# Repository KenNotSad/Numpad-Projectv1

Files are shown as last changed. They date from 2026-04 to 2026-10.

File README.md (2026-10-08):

# Numpad-Projectv1

This project is an RP2040-powered gasket-mount numpad with a rotary encoder and OLED display, intended to help me learn introductory PCB design and QMK firmware. 
<p align="center">
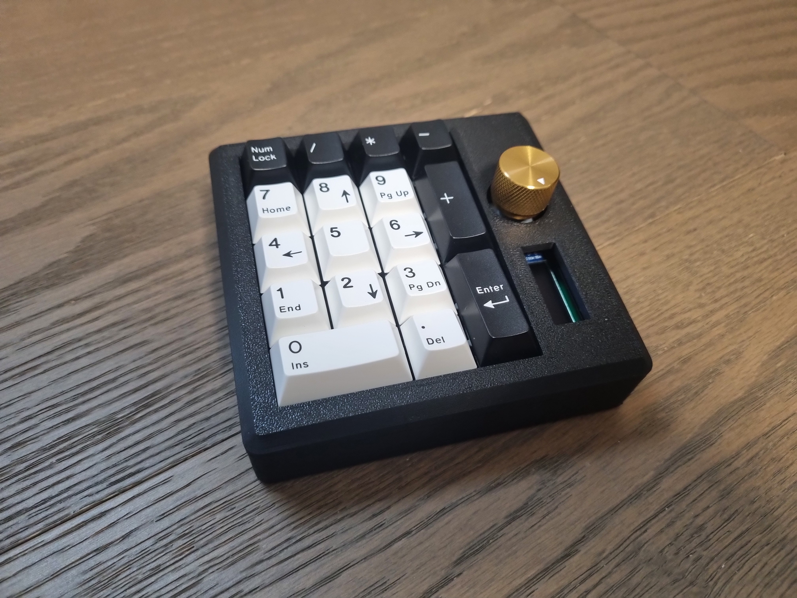
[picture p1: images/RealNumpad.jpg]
  
</p>

## Mechanical
<p align="center">
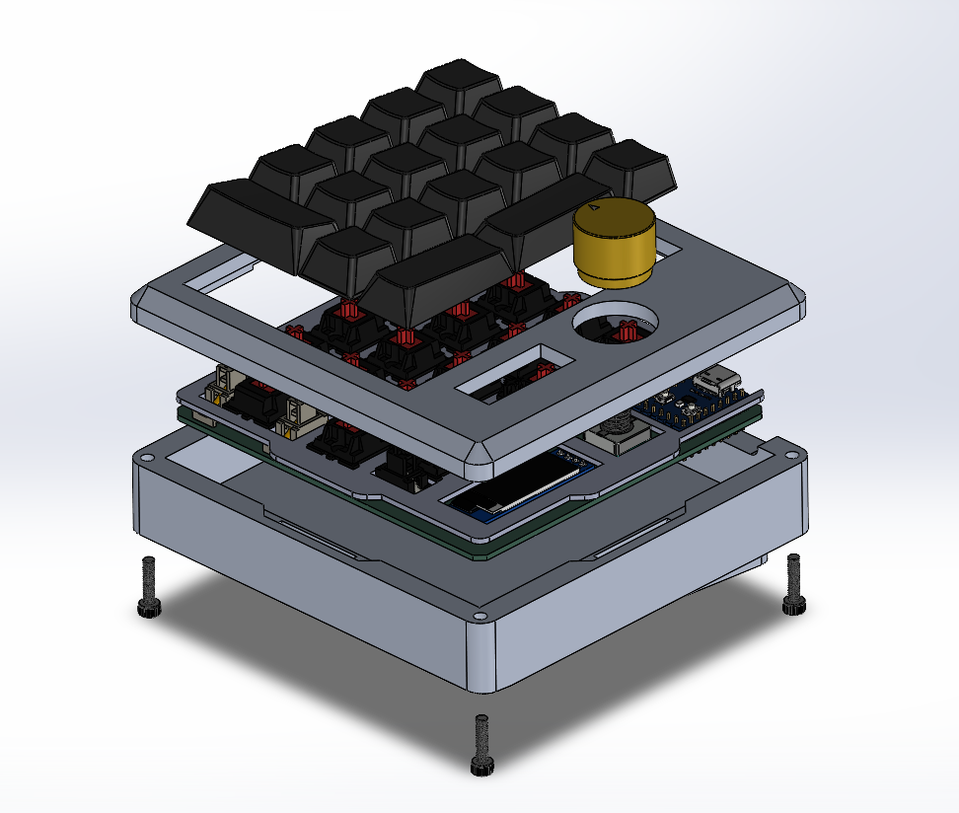
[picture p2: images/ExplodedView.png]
Exploded View
  
</p>
The top case, bottom case, and plate were designed in SolidWorks and 3D-printed. 

## Electrical
<p align="center">
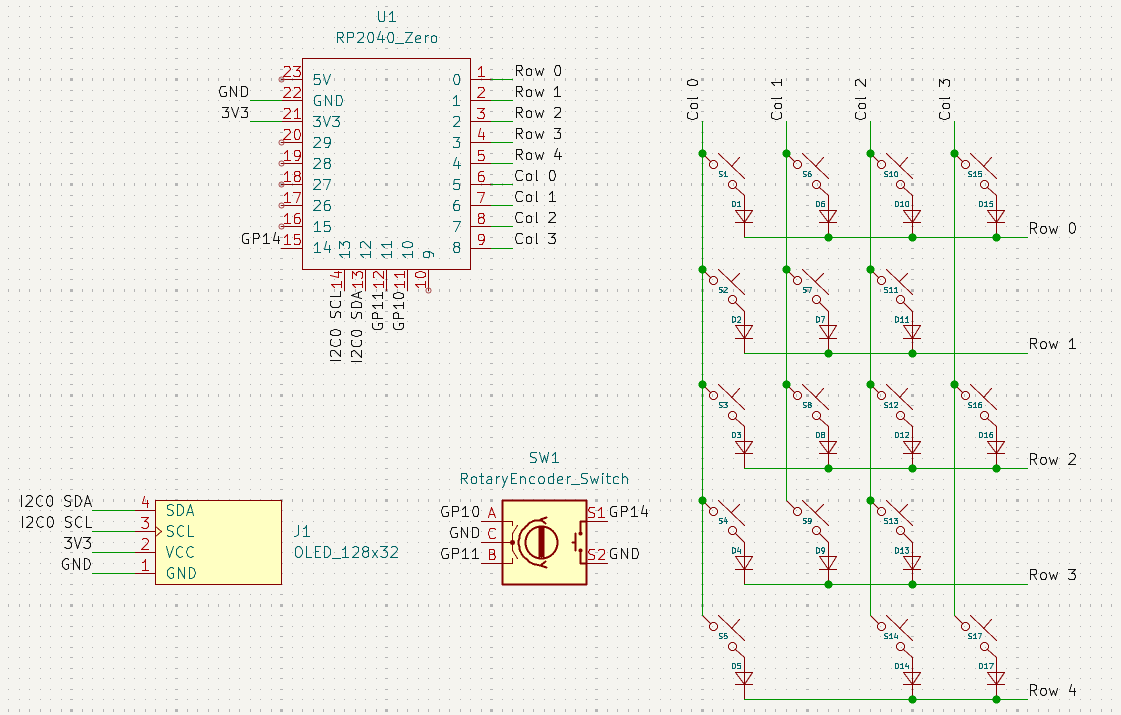
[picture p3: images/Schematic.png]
Schematic
  
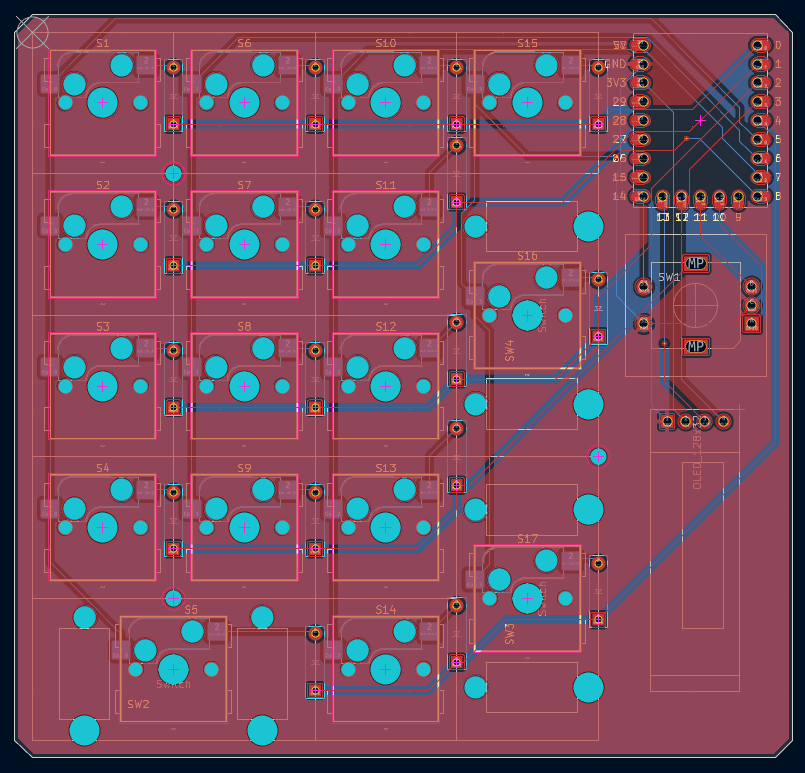
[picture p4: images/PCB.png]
PCB
  
</p>
Schematic and PCB were designed in KiCad and sent to be manufactured by JLCPCB. NOTE: The KiCad files rely on the ScottoKeebs KiCad Library. 

## Assembly

1. Solder RP2040 Zero, 1N4148 diodes, MX hotswap sockets, EC11 rotary encoder, 128X32 OLED display onto PCB
2. Add 3 2U screw-in stabilizers (1.6mm) to the PCB
3. Attach plate to PCB using 3mm standoffs and M2 x 3mm screws
4. Insert 17 MX switches into the assembly
5. Add 8 (4 on top case, 4 on bottom case) 3mm x 25mm x 1.5mm gaskets to the cases
6. Sandwich the plate between the top and bottom cases, and assemble using 4 M3 x 12mm screws
7. Add rubber feet (or tack) to the bottom case
8. Add keycaps and knob

Done!

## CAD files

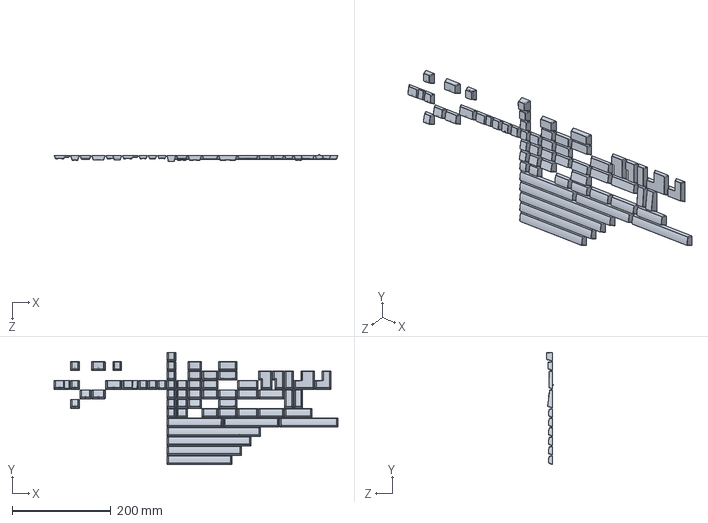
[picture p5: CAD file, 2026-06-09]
cad/Cherry Keycaps Full.SLDPRT
575.3 x 227.7 x 15.0 mm

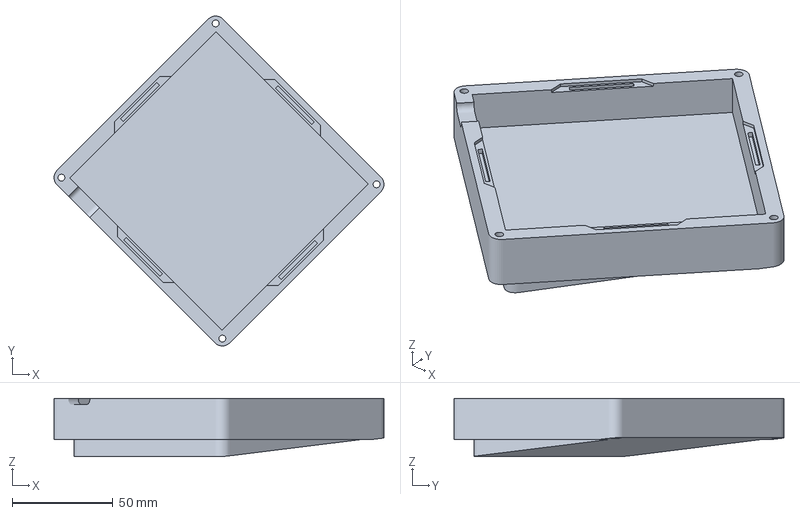
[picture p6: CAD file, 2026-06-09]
cad/Fabrication/BottomCasev1.3mf
163.5 x 163.5 x 29.0 mm

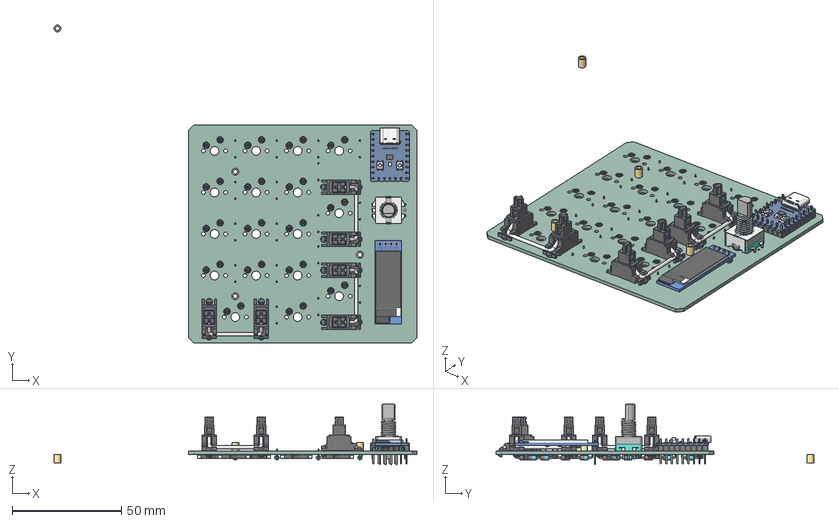
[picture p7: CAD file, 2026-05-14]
pcb/Numpadv1/PCB.step
166.5 x 145.9 x 27.8 mm
Hotswap_MX x 17
Stabilizer_MX_2.00u x 3
EC11
Standoff x 4
Raspberry_Pi_Pico.step
PinHeader_1x20_P2.54mm_Vertical.step
BOARD
ANSCHL_X_FCSSE_009
K_X_F6RPER_009
ANSCHL_X_FCSSE_010
K_X_F6RPER_010
EXTRUDED-32530
USER_LIBRARY-CHIP_CAP_MLCC_0219
USER_LIBRARY-CHIP_CAP_MLCC_0220
USER_LIBRARY-CHIP_CAP_MLCC_0221
USER_LIBRARY-CHIP_CAP_MLCC_0222
EXTRUDED-36548
USER_LIBRARY-RP2040_QFN56_04
USER_LIBRARY-8MA3_1
USER_LIBRARY-8MA3_2
EXTRUDED-175432
EXTRUDED-175808
EXTRUDED-175809
EXTRUDED-175810
EXTRUDED-175811
EXTRUDED-175812
ANSCHL_X_FCSSE_011
K_X_F6RPER_011
ANSCHL_X_FCSSE_012
K_X_F6RPER_012
ANSCHL_X_FCSSE_013
K_X_F6RPER_013
ANSCHL_X_FCSSE_014
K_X_F6RPER_014
ANSCHL_X_FCSSE_015
K_X_F6RPER_015
ANSCHL_X_FCSSE_016
K_X_F6RPER_016
ANSCHL_X_FCSSE_017
K_X_F6RPER_017
TS-1185EC-A-E-A-002
TS-1185EC-A-E-A-003
USER_LIBRARY-CHIP_CAP_MLCC_0223
USER_LIBRARY-CHIP_CAP_MLCC_0224
USER_LIBRARY-CHIP_CAP_MLCC_0225
USER_LIBRARY-CHIP_CAP_MLCC_0226
USER_LIBRARY-CHIP_CAP_MLCC_0227
USER_LIBRARY-CHIP_CAP_MLCC_0228
USER_LIBRARY-CHIP_CAP_MLCC_0229
USER_LIBRARY-CHIP_CAP_MLCC_0230
USER_LIBRARY-CHIP_CAP_MLCC_0231
USER_LIBRARY-CHIP_CAP_MLCC_0232
USER_LIBRARY-CHIP_CAP_MLCC_0233
USER_LIBRARY-CHIP_CAP_MLCC_0234
USER_LIBRARY-CHIP_CAP_MLCC_0235
USER_LIBRARY-CHIP_CAP_MLCC_0236
USER_LIBRARY-CHIP_CAP_MLCC_0237
EXTRUDED-374547
EXTRUDED-374548
EXTRUDED-374549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

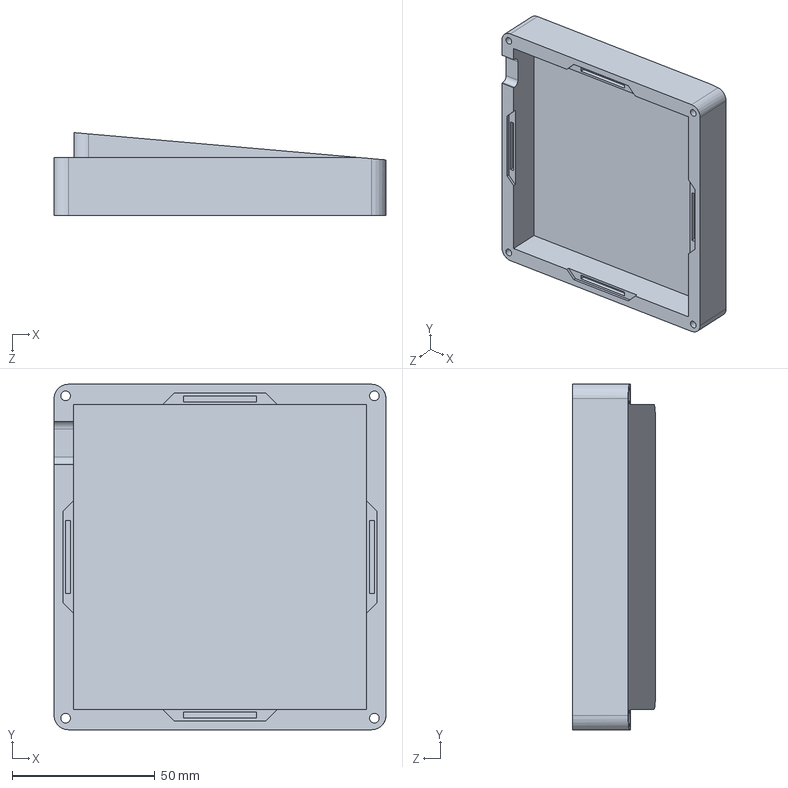
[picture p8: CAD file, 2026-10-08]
cad/Bottom Case.SLDPRT
116.2 x 120.9 x 29.0 mm

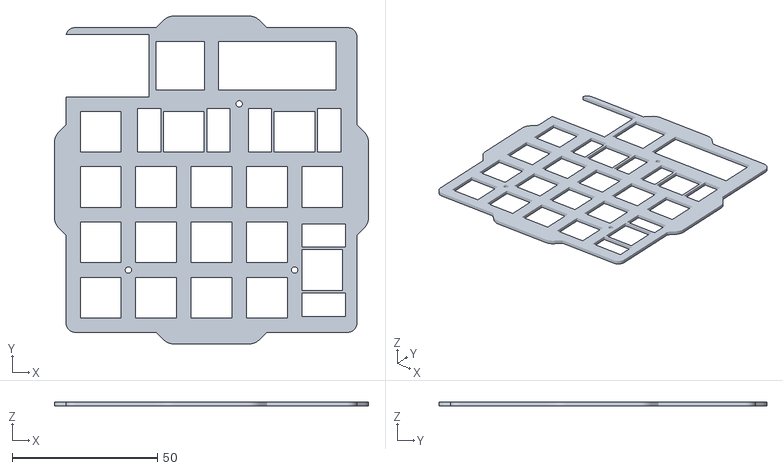
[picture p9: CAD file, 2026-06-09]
cad/Fabrication/Platev1.STL
108.0 x 112.8 x 1.50

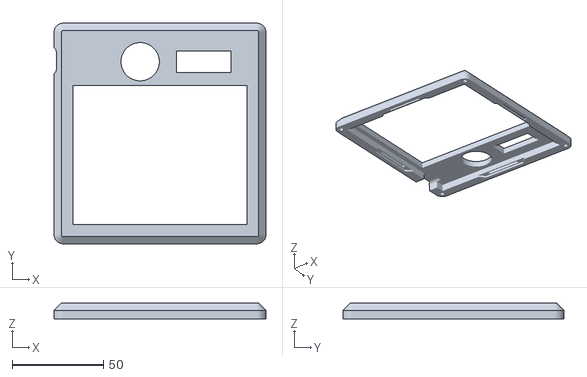
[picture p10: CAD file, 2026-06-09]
cad/Fabrication/TopCasev1.STL
116.2 x 120.9 x 8.75

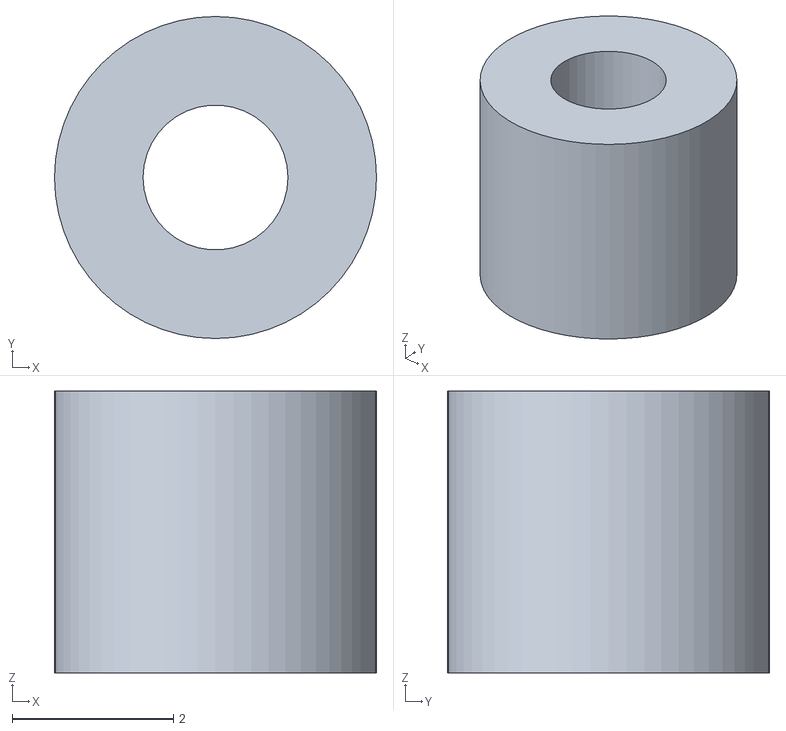
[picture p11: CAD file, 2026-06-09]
cad/Fabrication/standoff.STL
4.00 x 4.00 x 3.50

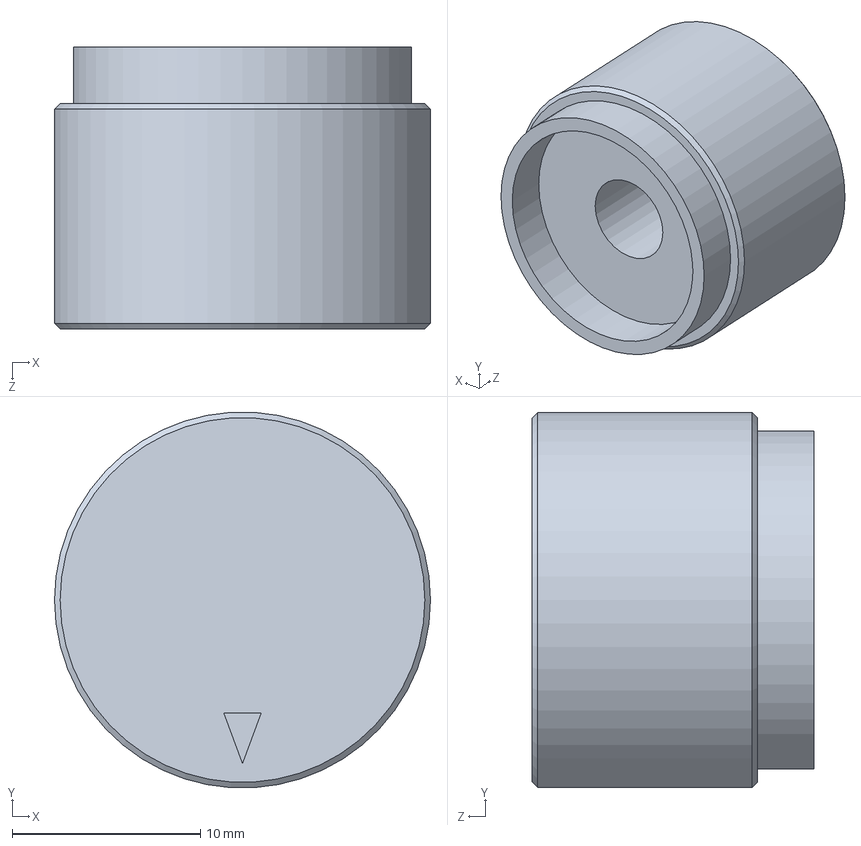
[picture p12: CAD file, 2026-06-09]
cad/Knob.SLDPRT
20.0 x 20.0 x 15.0 mm

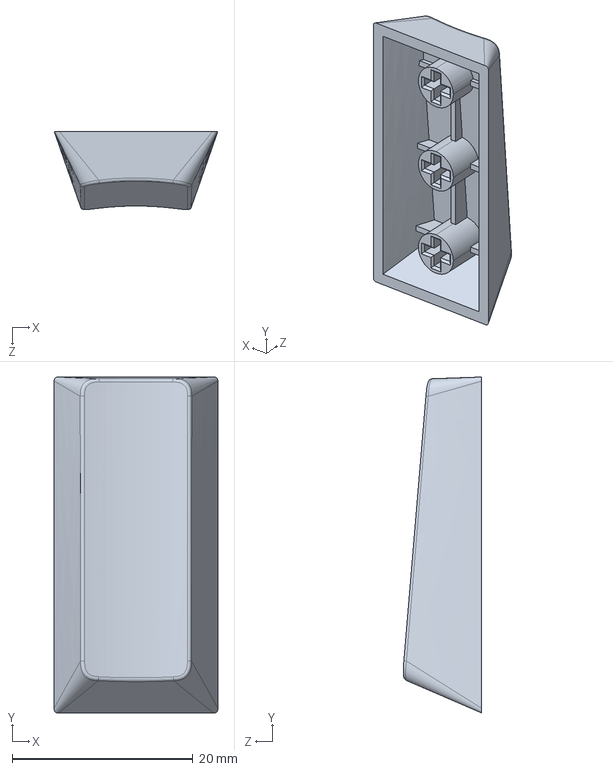
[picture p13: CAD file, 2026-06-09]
cad/R4_2u.SLDPRT
18.1 x 37.2 x 8.67 mm

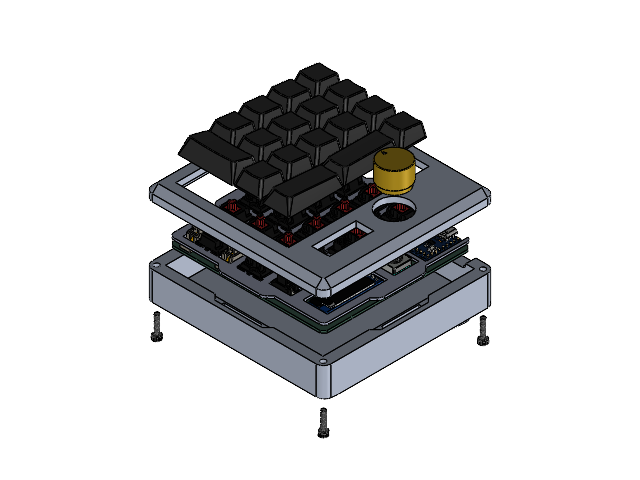
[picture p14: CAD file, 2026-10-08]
cad/Full Assembly.SLDASM
Bottom Case
ANSCHL_X_FCSSE_009.step
K_X_F6RPER_009.step
ANSCHL_X_FCSSE_010.step
K_X_F6RPER_010.step
EXTRUDED-32530.step
USER_LIBRARY-CHIP_CAP_MLCC_0219.step
USER_LIBRARY-CHIP_CAP_MLCC_0220.step
USER_LIBRARY-CHIP_CAP_MLCC_0221.step
USER_LIBRARY-CHIP_CAP_MLCC_0222.step
EXTRUDED-36548.step
USER_LIBRARY-RP2040_QFN56_04.step
USER_LIBRARY-8MA3_1.step
USER_LIBRARY-8MA3_2.step
EXTRUDED-175432.step
EXTRUDED-175808.step
EXTRUDED-175809.step
EXTRUDED-175810.step
EXTRUDED-175811.step
EXTRUDED-175812.step
SOLID-176303.step
SOLID-266517.step
SOLID-267632.step
SOLID-268682.step
SOLID-269938.step
SOLID-271125.step
SOLID-273528.step
SOLID-275954.step
SOLID-278237.step
SOLID-280543.step
SOLID-281855.step
SOLID-283075.step
SOLID-286630.step
SOLID-290701.step
SOLID-293585.step
SOLID-297797.step
SOLID-300887.step
SOLID-304461.step
SOLID-305782.step
SOLID-307195.step
SOLID-312211.step
SOLID-317292.step
ANSCHL_X_FCSSE_011.step
K_X_F6RPER_011.step
ANSCHL_X_FCSSE_012.step
K_X_F6RPER_012.step
ANSCHL_X_FCSSE_013.step
K_X_F6RPER_013.step
ANSCHL_X_FCSSE_014.step
K_X_F6RPER_014.step
ANSCHL_X_FCSSE_015.step
K_X_F6RPER_015.step
ANSCHL_X_FCSSE_016.step
K_X_F6RPER_016.step
ANSCHL_X_FCSSE_017.step
K_X_F6RPER_017.step
TS-1185EC-A-E-A-002.step
TS-1185EC-A-E-A-003.step
USER_LIBRARY-CHIP_CAP_MLCC_0223.step
USER_LIBRARY-CHIP_CAP_MLCC_0224.step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

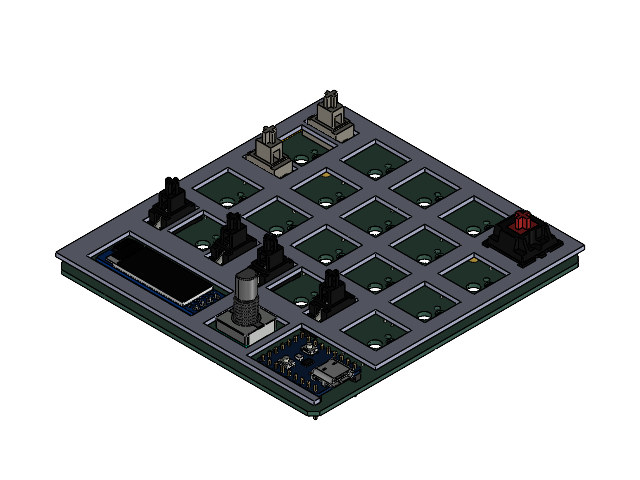
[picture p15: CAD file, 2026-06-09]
cad/Plate+PCB Assembly.SLDASM
ANSCHL_X_FCSSE_009.step
K_X_F6RPER_009.step
ANSCHL_X_FCSSE_010.step
K_X_F6RPER_010.step
EXTRUDED-32530.step
USER_LIBRARY-CHIP_CAP_MLCC_0219.step
USER_LIBRARY-CHIP_CAP_MLCC_0220.step
USER_LIBRARY-CHIP_CAP_MLCC_0221.step
USER_LIBRARY-CHIP_CAP_MLCC_0222.step
EXTRUDED-36548.step
USER_LIBRARY-RP2040_QFN56_04.step
USER_LIBRARY-8MA3_1.step
USER_LIBRARY-8MA3_2.step
EXTRUDED-175432.step
EXTRUDED-175808.step
EXTRUDED-175809.step
EXTRUDED-175810.step
EXTRUDED-175811.step
EXTRUDED-175812.step
SOLID-176303.step
SOLID-266517.step
SOLID-267632.step
SOLID-268682.step
SOLID-269938.step
SOLID-271125.step
SOLID-273528.step
SOLID-275954.step
SOLID-278237.step
SOLID-280543.step
SOLID-281855.step
SOLID-283075.step
SOLID-286630.step
SOLID-290701.step
SOLID-293585.step
SOLID-297797.step
SOLID-300887.step
SOLID-304461.step
SOLID-305782.step
SOLID-307195.step
SOLID-312211.step
SOLID-317292.step
ANSCHL_X_FCSSE_011.step
K_X_F6RPER_011.step
ANSCHL_X_FCSSE_012.step
K_X_F6RPER_012.step
ANSCHL_X_FCSSE_013.step
K_X_F6RPER_013.step
ANSCHL_X_FCSSE_014.step
K_X_F6RPER_014.step
ANSCHL_X_FCSSE_015.step
K_X_F6RPER_015.step
ANSCHL_X_FCSSE_016.step
K_X_F6RPER_016.step
ANSCHL_X_FCSSE_017.step
K_X_F6RPER_017.step
TS-1185EC-A-E-A-002.step
TS-1185EC-A-E-A-003.step
USER_LIBRARY-CHIP_CAP_MLCC_0223.step
USER_LIBRARY-CHIP_CAP_MLCC_0224.step
USER_LIBRARY-CHIP_CAP_MLCC_0225.step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

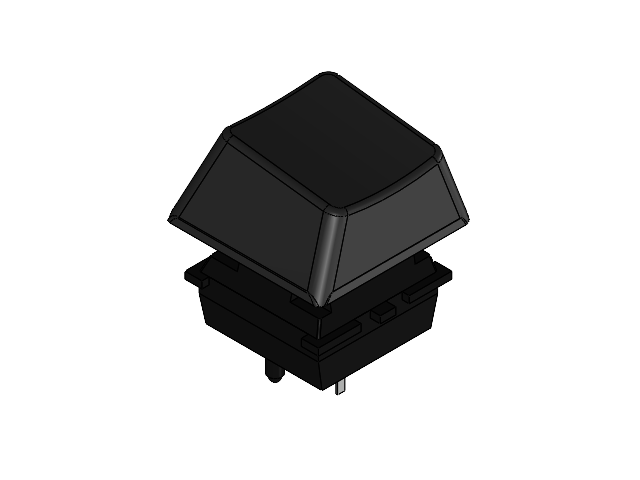
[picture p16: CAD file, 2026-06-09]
cad/Switch + Keycap.SLDASM
Component1.step
Component2.step
Cherry MX Keycap

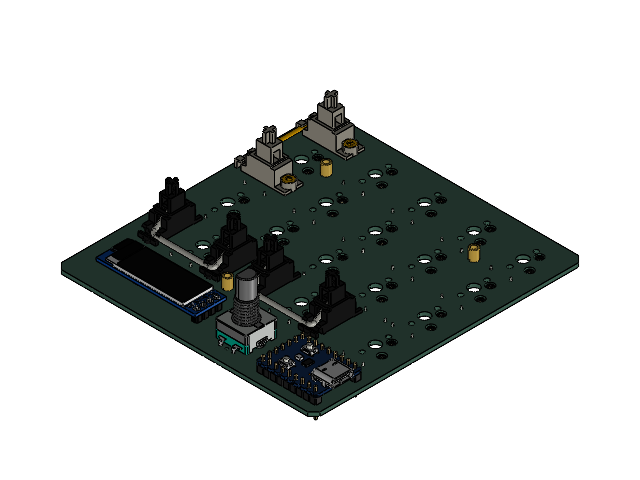
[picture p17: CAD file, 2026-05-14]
cad/PCB.SLDASM
ANSCHL_X_FCSSE_009.step
K_X_F6RPER_009.step
ANSCHL_X_FCSSE_010.step
K_X_F6RPER_010.step
EXTRUDED-32530.step
USER_LIBRARY-CHIP_CAP_MLCC_0219.step
USER_LIBRARY-CHIP_CAP_MLCC_0220.step
USER_LIBRARY-CHIP_CAP_MLCC_0221.step
USER_LIBRARY-CHIP_CAP_MLCC_0222.step
EXTRUDED-36548.step
USER_LIBRARY-RP2040_QFN56_04.step
USER_LIBRARY-8MA3_1.step
USER_LIBRARY-8MA3_2.step
EXTRUDED-175432.step
EXTRUDED-175808.step
EXTRUDED-175809.step
EXTRUDED-175810.step
EXTRUDED-175811.step
EXTRUDED-175812.step
SOLID-176303.step
SOLID-266517.step
SOLID-267632.step
SOLID-268682.step
SOLID-269938.step
SOLID-271125.step
SOLID-273528.step
SOLID-275954.step
SOLID-278237.step
SOLID-280543.step
SOLID-281855.step
SOLID-283075.step
SOLID-286630.step
SOLID-290701.step
SOLID-293585.step
SOLID-297797.step
SOLID-300887.step
SOLID-304461.step
SOLID-305782.step
SOLID-307195.step
SOLID-312211.step
SOLID-317292.step
ANSCHL_X_FCSSE_011.step
K_X_F6RPER_011.step
ANSCHL_X_FCSSE_012.step
K_X_F6RPER_012.step
ANSCHL_X_FCSSE_013.step
K_X_F6RPER_013.step
ANSCHL_X_FCSSE_014.step
K_X_F6RPER_014.step
ANSCHL_X_FCSSE_015.step
K_X_F6RPER_015.step
ANSCHL_X_FCSSE_016.step
K_X_F6RPER_016.step
ANSCHL_X_FCSSE_017.step
K_X_F6RPER_017.step
TS-1185EC-A-E-A-002.step
TS-1185EC-A-E-A-003.step
USER_LIBRARY-CHIP_CAP_MLCC_0223.step
USER_LIBRARY-CHIP_CAP_MLCC_0224.step
USER_LIBRARY-CHIP_CAP_MLCC_0225.step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

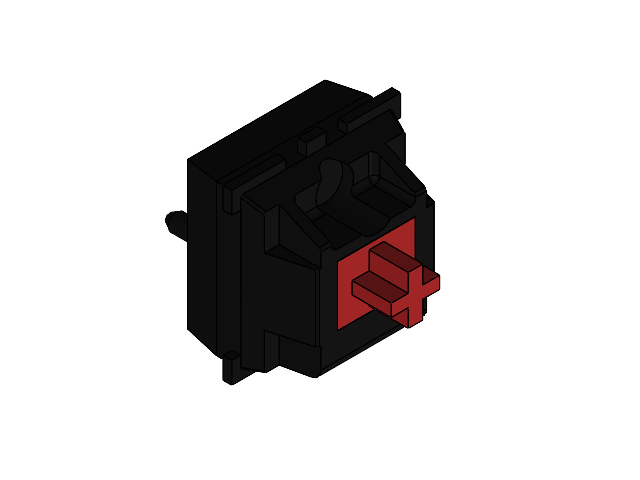
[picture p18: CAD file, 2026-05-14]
cad/MXSwitch.SLDASM
Component1.step
Component2.step

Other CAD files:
cad/Top Case.SLDPRT
cad/Fabrication/Plate.STEP
cad/Plate.SLDPRT
cad/standoffs.SLDPRT
cad/-R5_2u[1].SLDPRT
cad/Cherry MX Keycap.SLDPRT
cad/Fabrication/BottomCasev1.STL
cad/Plate.SLDDRW
cad/PlateTemplate.SLDPRT
cad/R2-3_2u.SLDPRT
cad/switch.step

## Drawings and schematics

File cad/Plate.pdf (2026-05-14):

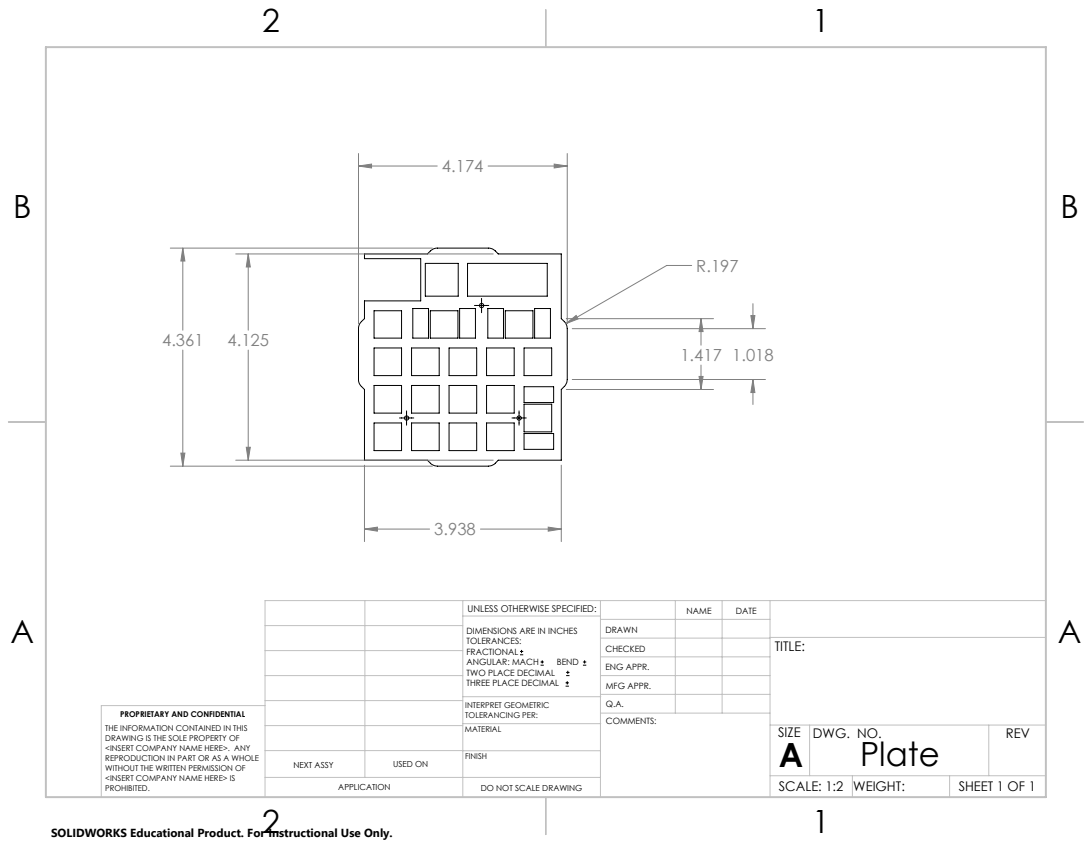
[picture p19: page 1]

UNLESS OTHERWISE SPECIFIED: | | NAME | DATE
DIMENSIONS ARE IN INCHES TOLERANCES: FRACTIONAL ANGULAR: MACH BEND TWO PLACE DECIMAL THREE PLACE DECIMAL | DRAWN

CHECKED | | | TITLE:

ENG APPR.
MFG APPR.

INTERPRET GEOMETRIC TOLERANCING PER: | Q.A.
MATERIAL | | SIZE A | DWG. NO. Plate | REV

PROPRIETARY AND CONFIDENTIAL
THE INFORMATION CONTAINED IN THIS
DRAWING IS THE SOLE PROPERTY OF
<INSERT COMPANY NAME HERE>. ANY
REPRODUCTION IN PART OR AS A WHOLE
WITHOUT THE WRITTEN PERMISSION OF
<INSERT COMPANY NAME HERE> IS
PROHIBITED.

NEXT ASSY | USED ON | FINISH

APPLICATION | DO NOT SCALE DRAWING | | SCALE: 1:2 | WEIGHT: | SHEET 1 OF 1

SOLIDWORKS Educational Product. For Instructional Use Only.

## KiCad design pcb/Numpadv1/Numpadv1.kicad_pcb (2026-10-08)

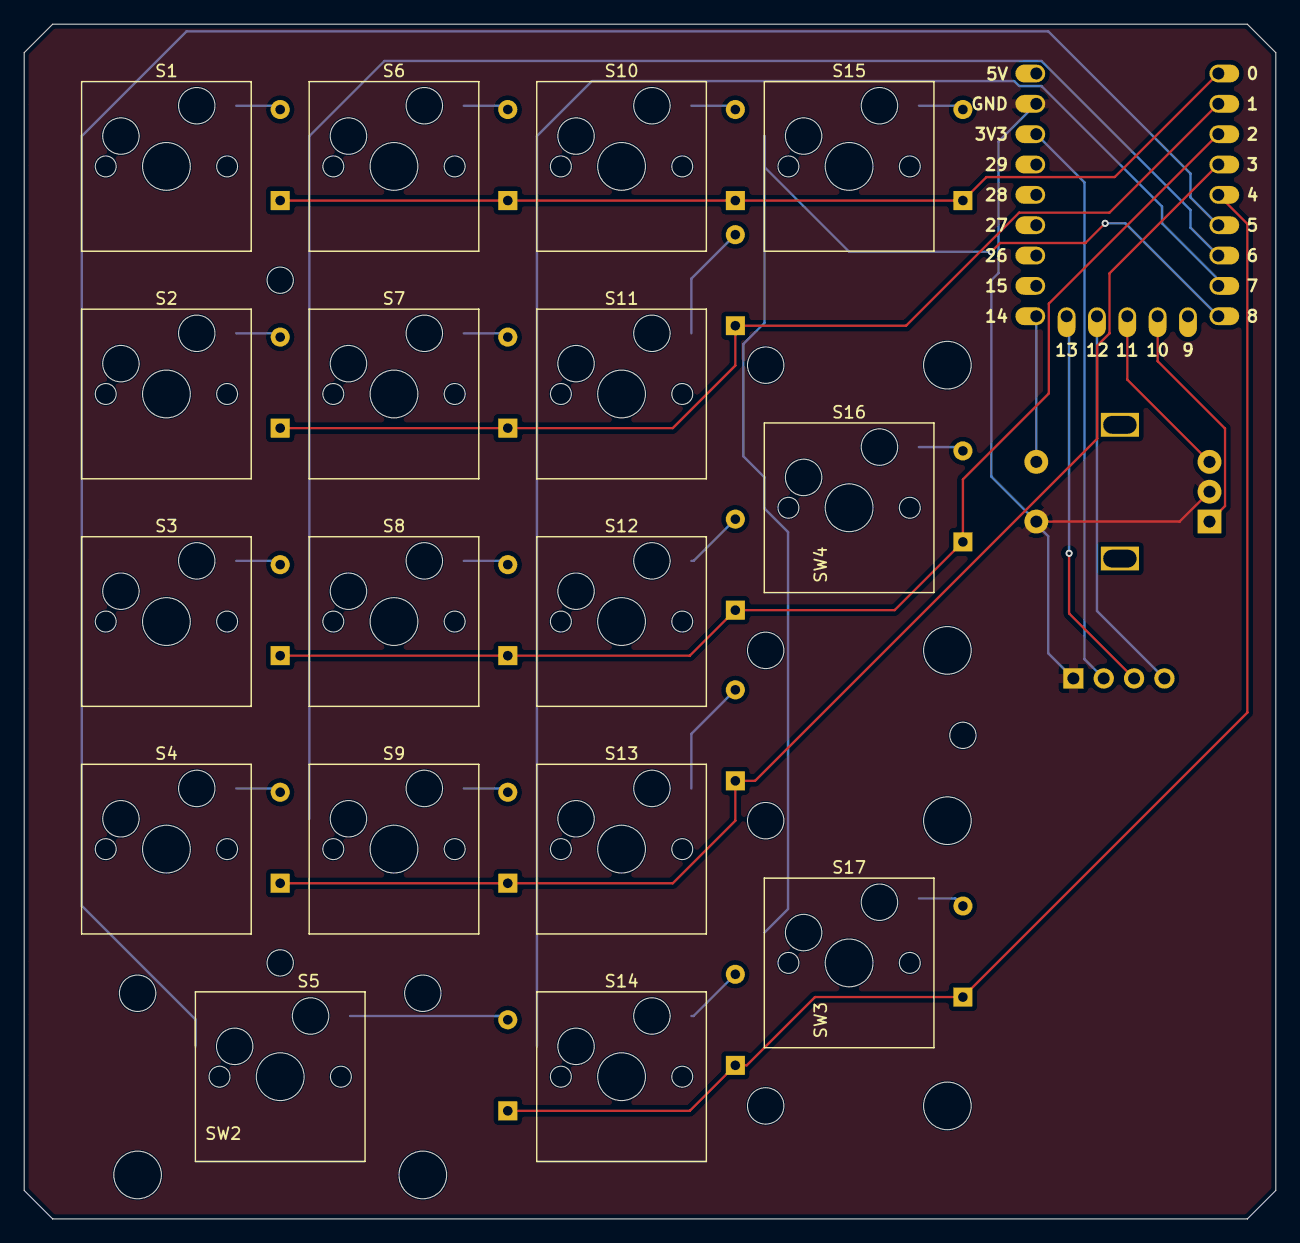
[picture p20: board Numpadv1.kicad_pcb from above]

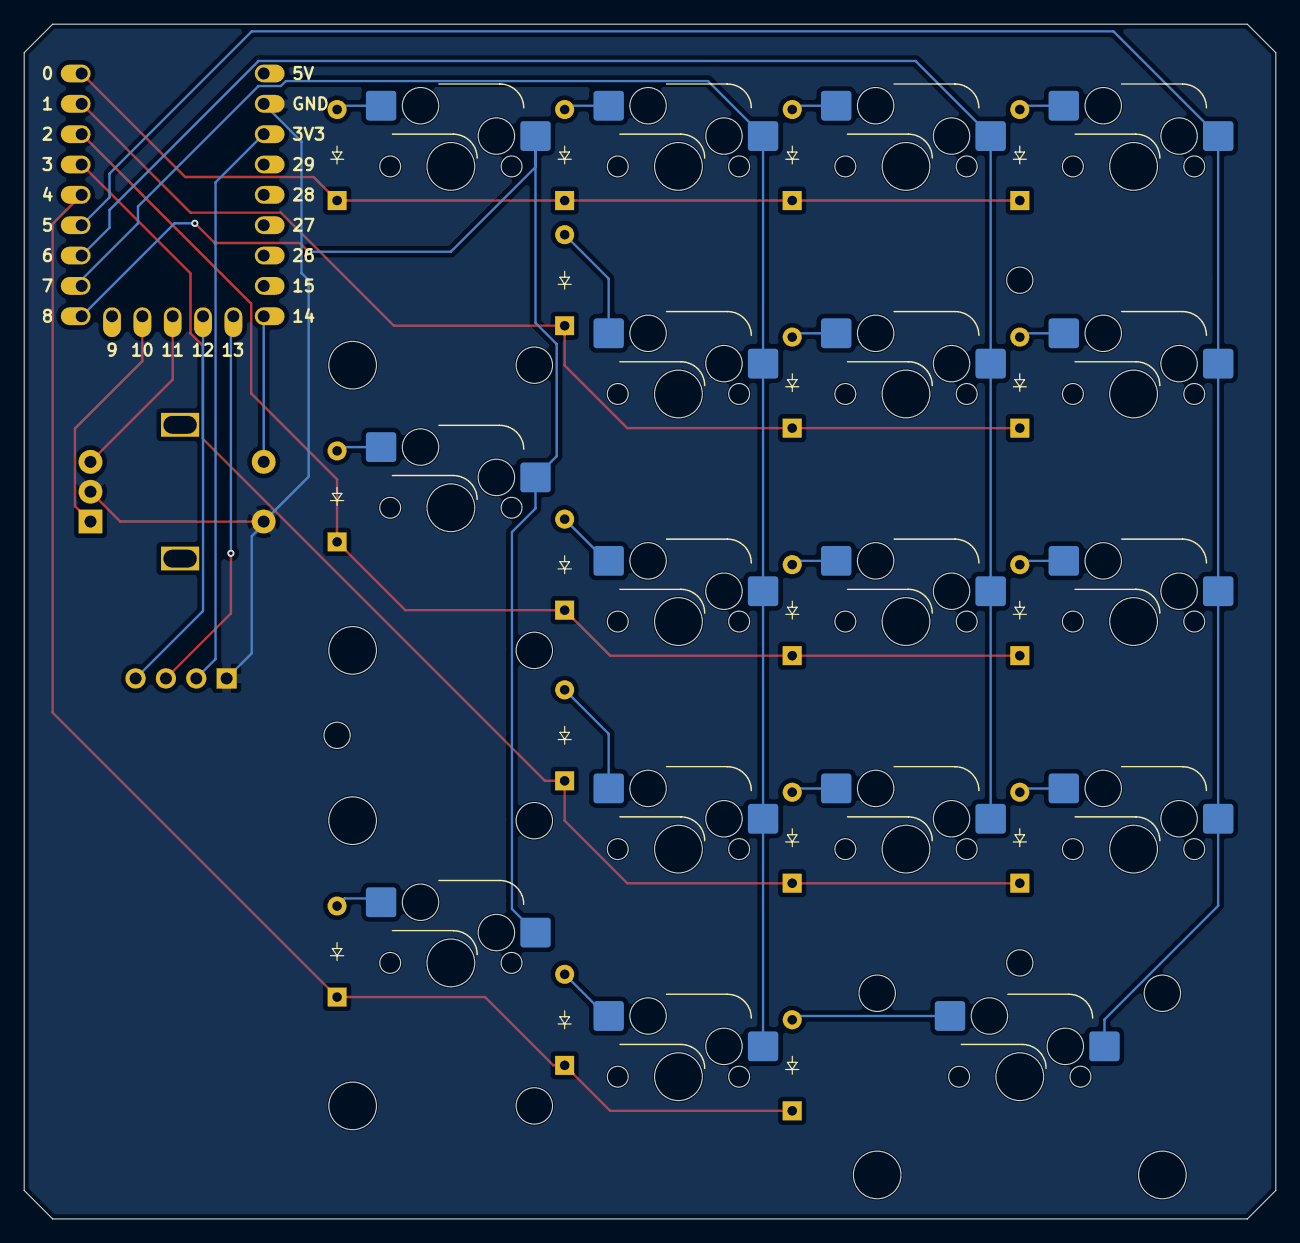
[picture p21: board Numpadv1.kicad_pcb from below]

Board: 2 copper layers, 104.8 x 100.0 mm, 44 parts (20 on the bottom side), 33 nets.

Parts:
D1, D2, D3, D4, D5, D6, D7, D8, D9, D10, D11, D12, D13, D14, D15, D16, D17: Diode_DO-35
H1, H2, H3, H4: Standoff_M2x4mm
J1: OLED_128x32
S1, S2, S3, S4, S6, S7, S8, S9, S10, S11, S12, S13, S14, S15: Hotswap_MX_1.00u
S5: Hotswap_MX_2.00u
S16, S17: Hotswap_MX_2.00u_90deg
SW1: RotaryEncoder_Switch; Encoder_EC11_MX
SW2, SW3, SW4: Switch; Stabilizer_MX_2.00u
U1: RP2040_Zero

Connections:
/3V3: J1.2 (VCC), U1.21 (3V3)
/Col 0: S1.1, S2.1, S3.1, S4.1, S5.1, U1.6 (5)
/Col 1: S6.1, S7.1, S8.1, S9.1, U1.7 (6)
/Col 2: S10.1, S11.1, S12.1, S13.1, S14.1, U1.8 (7)
/Col 3: S15.1, S16.1, S17.1, U1.9 (8)
/GND: J1.1 (GND), SW1.C, SW1.S2, U1.22 (GND)
/GP10: SW1.A, U1.11 (10)
/GP11: SW1.B, U1.12 (11)
/GP14: SW1.S1, U1.15 (14)
/I2C0 SCL: J1.3 (SCL), U1.14 (13)
/I2C0 SDA: J1.4 (SDA), U1.13 (12)
/Row 0: D1.1 (K), D6.1 (K), D10.1 (K), D15.1 (K), U1.1 (0)
/Row 1: D2.1 (K), D7.1 (K), D11.1 (K), U1.2 (1)
/Row 2: D3.1 (K), D8.1 (K), D12.1 (K), D16.1 (K), U1.3 (2)
/Row 3: D4.1 (K), D9.1 (K), D13.1 (K), U1.4 (3)
/Row 4: D5.1 (K), D14.1 (K), D17.1 (K), U1.5 (4)
unnamed: D1.2 (A), S1.2
unnamed: D2.2 (A), S2.2
unnamed: D3.2 (A), S3.2
unnamed: D4.2 (A), S4.2
unnamed: D5.2 (A), S5.2
unnamed: D6.2 (A), S6.2
unnamed: D7.2 (A), S7.2
unnamed: D8.2 (A), S8.2
unnamed: D9.2 (A), S9.2
unnamed: D10.2 (A), S10.2
unnamed: D11.2 (A), S11.2
unnamed: D12.2 (A), S12.2
unnamed: D13.2 (A), S13.2
unnamed: D14.2 (A), S14.2
unnamed: D15.2 (A), S15.2
unnamed: D16.2 (A), S16.2
unnamed: D17.2 (A), S17.2

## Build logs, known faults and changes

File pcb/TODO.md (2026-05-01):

# TODO
- [ x ] Design Schematics
- [ ] Design PCB
    - [ ] Rotary Knob?

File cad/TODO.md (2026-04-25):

# TODO
- [ ] Design Top Case
- [ ] Design Bottom Case
- [ ] Design Plate

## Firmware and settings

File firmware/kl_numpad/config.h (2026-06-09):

// Copyright 2022 Stefan Kerkmann
// SPDX-License-Identifier: GPL-2.0-or-later

#pragma once

#define RP2040_BOOTLOADER_DOUBLE_TAP_RESET
#define RP2040_BOOTLOADER_DOUBLE_TAP_RESET_LED GP25
#define RP2040_BOOTLOADER_DOUBLE_TAP_RESET_TIMEOUT 500U

/* Encoder Input */
#define ENCODER_BTN_PIN GP13
#define ENCODER_DIRECTION_FLIP

/* OLED */
#define OLED_DISPLAY_128X32 

#define I2C_DRIVER I2CD1
#define I2C1_SDA_PIN GP11 
#define I2C1_SCL_PIN GP12

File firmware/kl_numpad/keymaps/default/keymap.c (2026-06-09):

#include QMK_KEYBOARD_H
#include "gpio.h"

const uint16_t PROGMEM keymaps[][MATRIX_ROWS][MATRIX_COLS] = {
    [0] = LAYOUT(
        KC_NUM,  KC_PSLS, KC_PAST, KC_PMNS,
        KC_P7,   KC_P8,   KC_P9,
        KC_P4,   KC_P5,   KC_P6,   KC_PPLS,
        KC_P1,   KC_P2,   KC_P3,
        KC_P0,             KC_DOT, KC_PENT
    )
};

bool encoder_update_user(uint8_t index, bool clockwise) {
    if (clockwise) {
        tap_code(KC_VOLU);
    } else {
        tap_code(KC_VOLD);
    }

    return true;
}

void keyboard_post_init_user(void) {
    gpio_set_pin_input_high(ENCODER_BTN_PIN);
}

void matrix_scan_user(void) {
    static bool pressed = false;

    if (!gpio_read_pin(ENCODER_BTN_PIN)) {
        if (!pressed) {
            tap_code(KC_MPLY);
            pressed = true;
        }
    } else {
        pressed = false;
    }
}

#ifdef OLED_ENABLE

bool oled_task_user(void) {
    oled_clear();

    oled_write_ln("KL NUMPAD", false);
    oled_write_ln("", false);

    oled_write_ln("Volume Knob", false);

    if (host_keyboard_led_state().num_lock) {
        oled_write_ln("NUMLOCK ON", false);
    } else {
        oled_write_ln("NUMLOCK OFF", false);
    }

    return false;
}

#endif

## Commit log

2026-05-01 Schematics + PCB
    [Numpadv1.kicad_pcb, Numpadv1.kicad_sch]
2026-05-01 PCB UPDATED
2026-05-07 PCB Completed (for now)
    [Numpadv1.kicad_pcb, Numpadv1.kicad_sch]
2026-05-14 Filled Zones
    [Bottom Case.SLDPRT, Full Assembly.SLDASM, MXSwitch.SLDASM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]
2026-06-09 External Cad Files
    [-R5_2u[1].SLDPRT, Cherry MX Keycap.SLDPRT, R2-3_2u.SLDPRT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]
2026-06-09 CAD Complete
    [Bottom Case.SLDPRT, Cherry Keycaps Full.SLDPRT, Full Assembly.SLDASM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]
2026-06-09 3D Printed Files
    [BottomCasev1.3mf, BottomCasev1.STL, Platev1.STL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]
2026-06-09 PCB Manufacturing Files
    [Numpadv1-B_Cu.gbl, Numpadv1-B_Mask.gbs, Numpadv1-B_Paste.gbp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]
2026-06-20 Updated README.md
    Added note about reliance on ScottoKeebs KiCad Library.
2026-10-08 Routing Fixed
    [Bottom Case.SLDPRT, Full Assembly.SLDASM, Numpadv1.kicad_pcb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]
